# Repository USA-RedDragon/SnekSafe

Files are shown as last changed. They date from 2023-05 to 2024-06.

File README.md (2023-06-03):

# SnekSafe

Keep your snek safe by controlling temperature and lighting.

## Assembled v1.1 Board

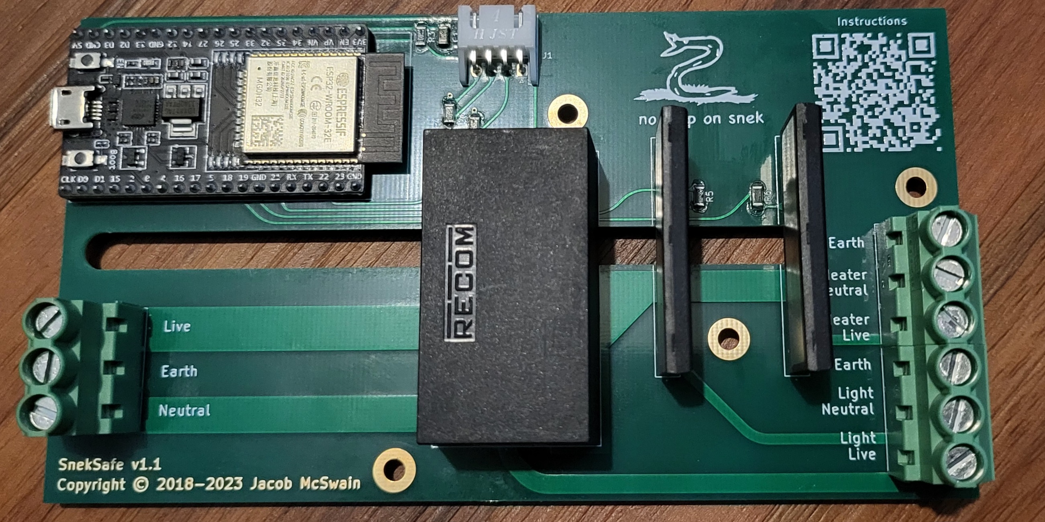
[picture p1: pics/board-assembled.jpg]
v1.1 assembled

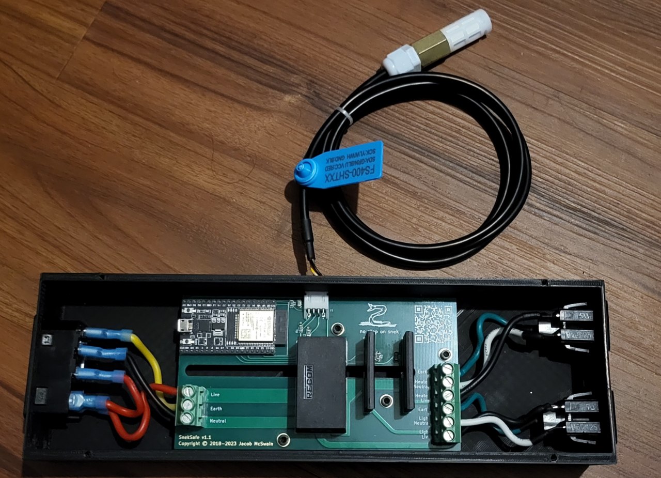
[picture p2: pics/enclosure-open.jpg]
v1.1 assembled in enclosure


## Board Renders

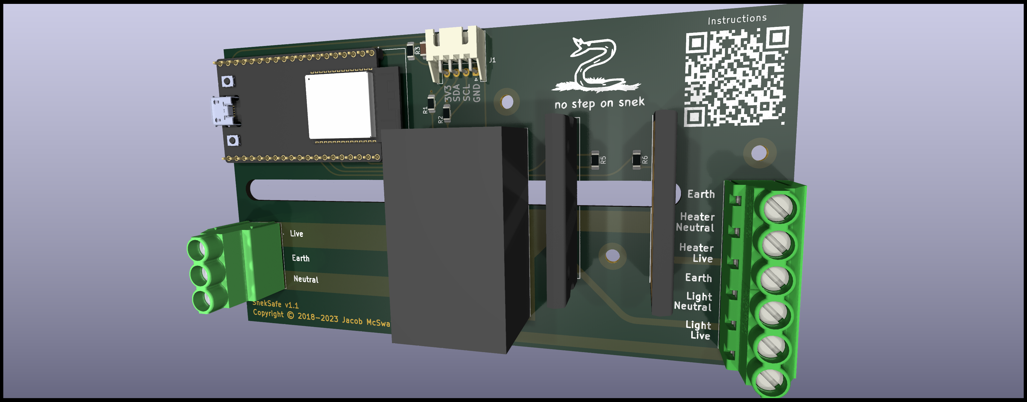
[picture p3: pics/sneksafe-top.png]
Board Top

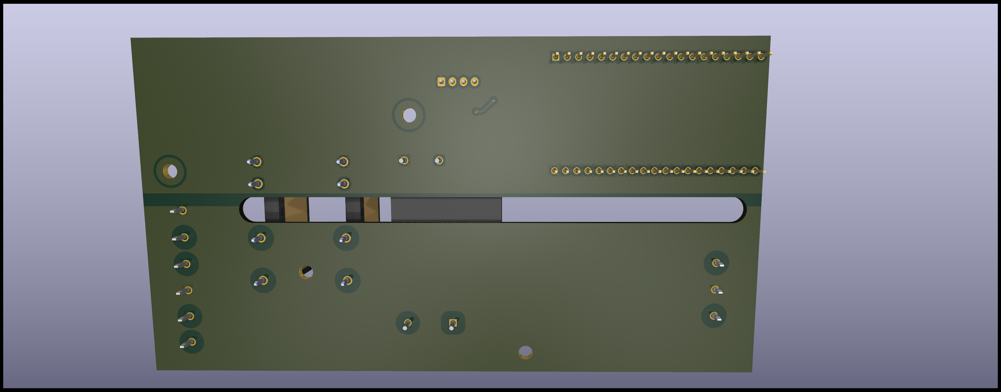
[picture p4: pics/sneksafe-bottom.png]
Board Bottom

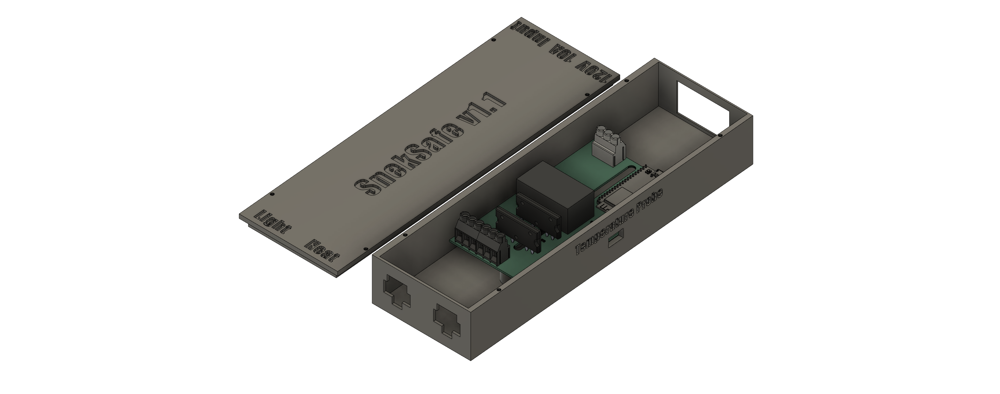
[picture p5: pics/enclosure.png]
Board Enclosure


## Schematic

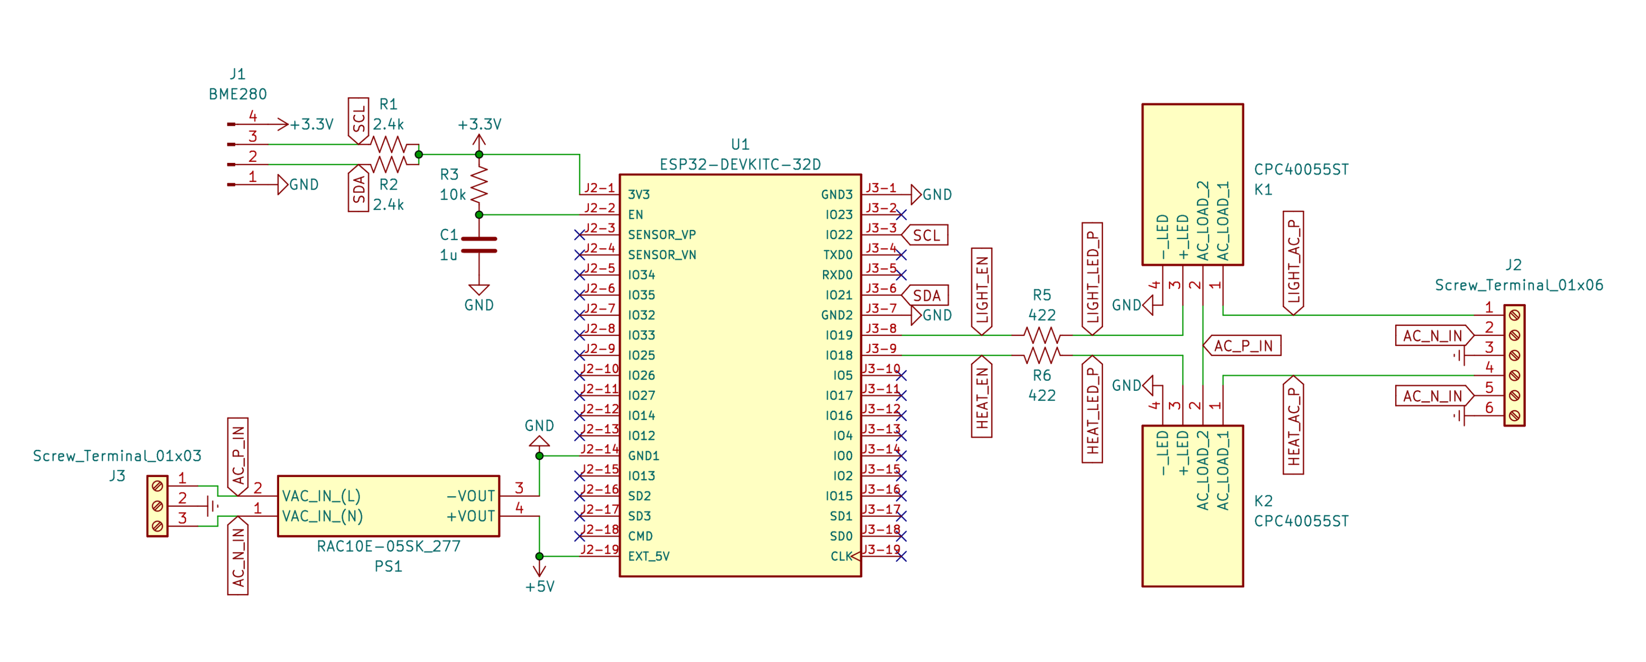
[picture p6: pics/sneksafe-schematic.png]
Schematic


## Board Layout

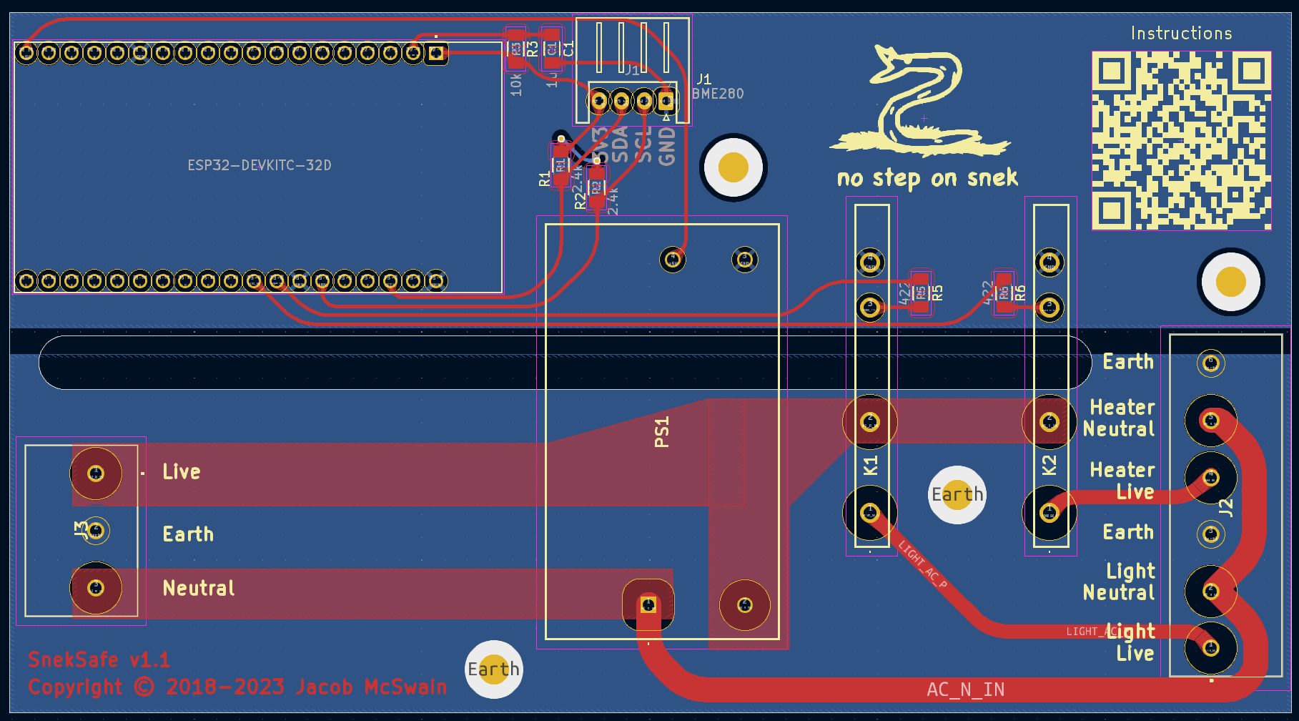
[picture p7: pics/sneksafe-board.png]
Board Layout


## Site Images

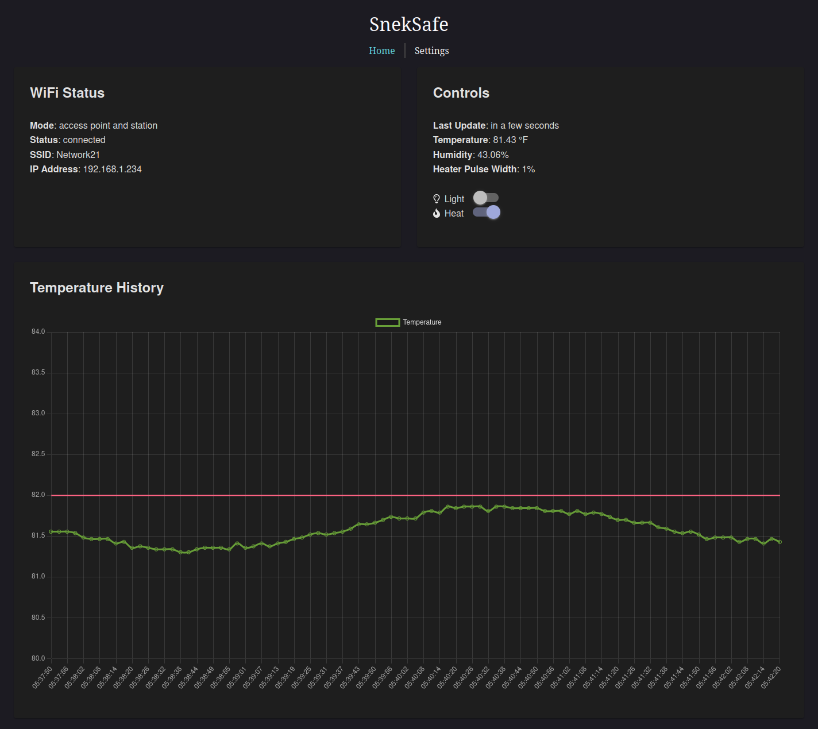
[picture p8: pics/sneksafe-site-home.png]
Home

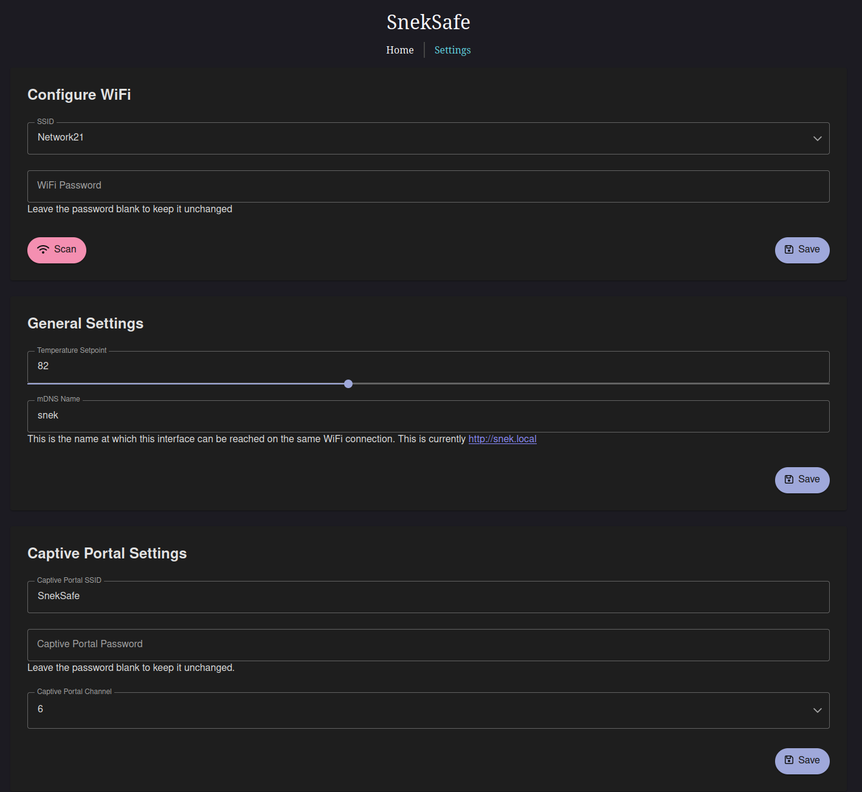
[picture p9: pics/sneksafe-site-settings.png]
Settings


## Parts not in the BOM that you might need

- 14AWG Silicone Wire - <https://www.amazon.com/dp/B089CRKSNN>
- Spade connectors for 14AWG - <https://www.amazon.com/dp/B08BZ972B5>
- 24AWG 4-conductor wire - <https://www.amazon.com/dp/B0BYDTCZ61>
- JST XH crimpers
- Heat shrink
- A 3d printer

## Cost

The one-off BOM cost, assuming you have spade connectors and 14AWG wire on hand is $121.25.

## On ESP32 choice

I chose the official ESP32-DevKitC-32E (ESP32-DevKitC V4) board due to quality. For some reason, on a cheaper NodeMCU ESP32S I was able to scan less WiFi networks and got a lower effective range.

## Premade Carts

A few items, such as the C13 AC cord, the C14 AC plug, and the panel mount AC outlets must be sourced on your own, as DigiKey and Mouser don't sell these commonly.

### JST XH Plug Parts

Mouser doesn't stock these: <https://www.digikey.com/short/1hzrmn3b>

### Mouser

<https://www.mouser.com/ProjectManager/ProjectDetail.aspx?AccessID=c3308da5f2>

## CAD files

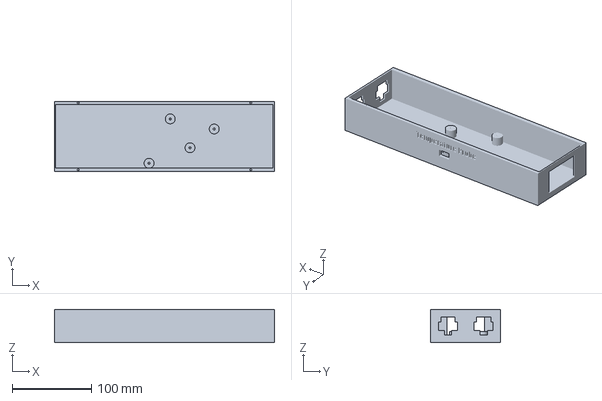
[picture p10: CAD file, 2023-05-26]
enclosure/body.3mf
278.0 x 89.0 x 42.0 mm

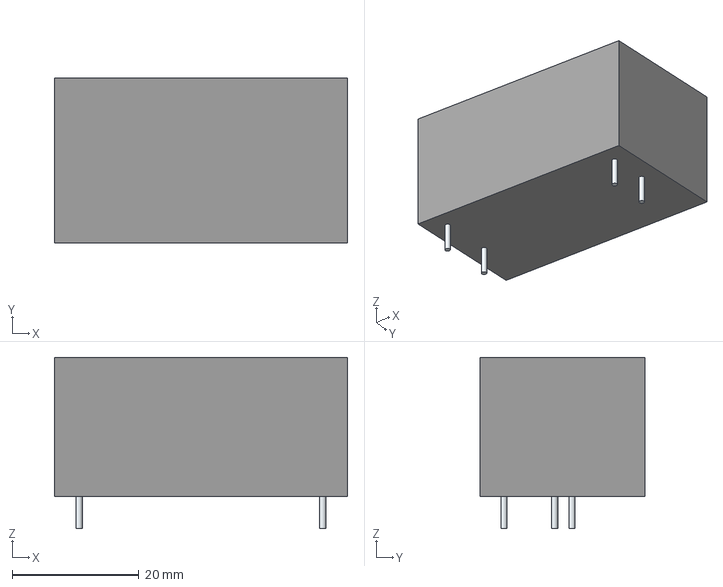
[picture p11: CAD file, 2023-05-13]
kicad/parts/RAC10E-05SK_277/RAC10E-05SK_277.stp
46.3 x 26.0 x 27.1 mm
Leads

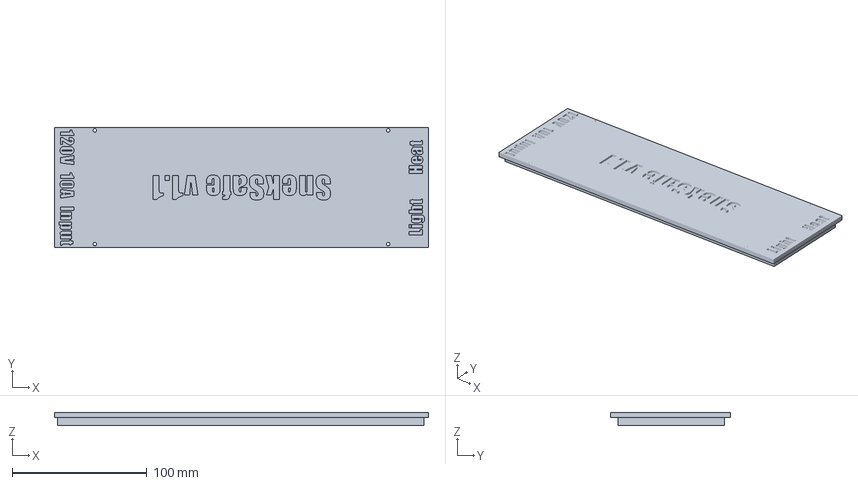
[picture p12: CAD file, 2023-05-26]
enclosure/lid.3mf
278.0 x 89.0 x 10.0 mm

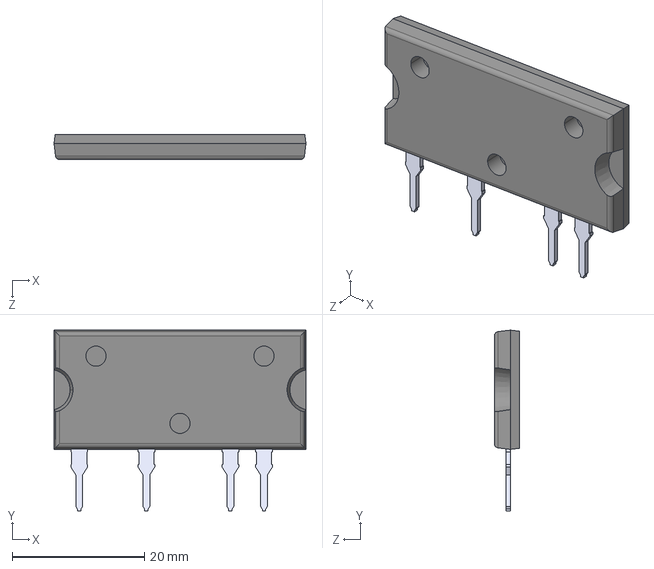
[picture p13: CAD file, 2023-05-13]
kicad/parts/CPC40055ST/CPC40055ST.stp
38.1 x 27.3 x 3.81 mm

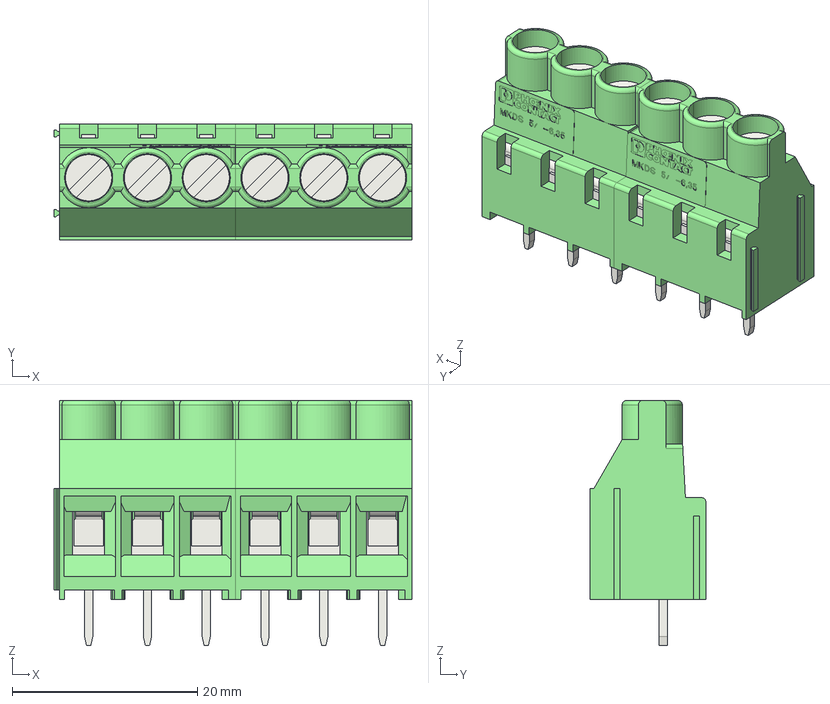
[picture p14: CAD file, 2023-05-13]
kicad/parts/Phoenix 1713969/1713969.stp
38.7 x 12.5 x 26.5 mm
KK_MKDS_5.1 x 6
AC_MKDS_5_Laengsschlitz x 6
LP_MKDS_5_5_00.1 x 6
AT_MKDS_5_6_35 x 2

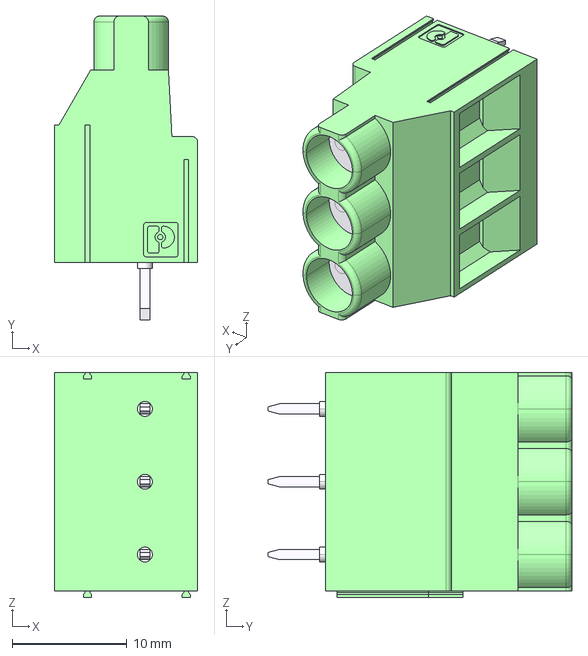
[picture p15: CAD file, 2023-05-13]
kicad/parts/Phoenix 1714968/1714968.stp
12.5 x 26.5 x 19.6 mm

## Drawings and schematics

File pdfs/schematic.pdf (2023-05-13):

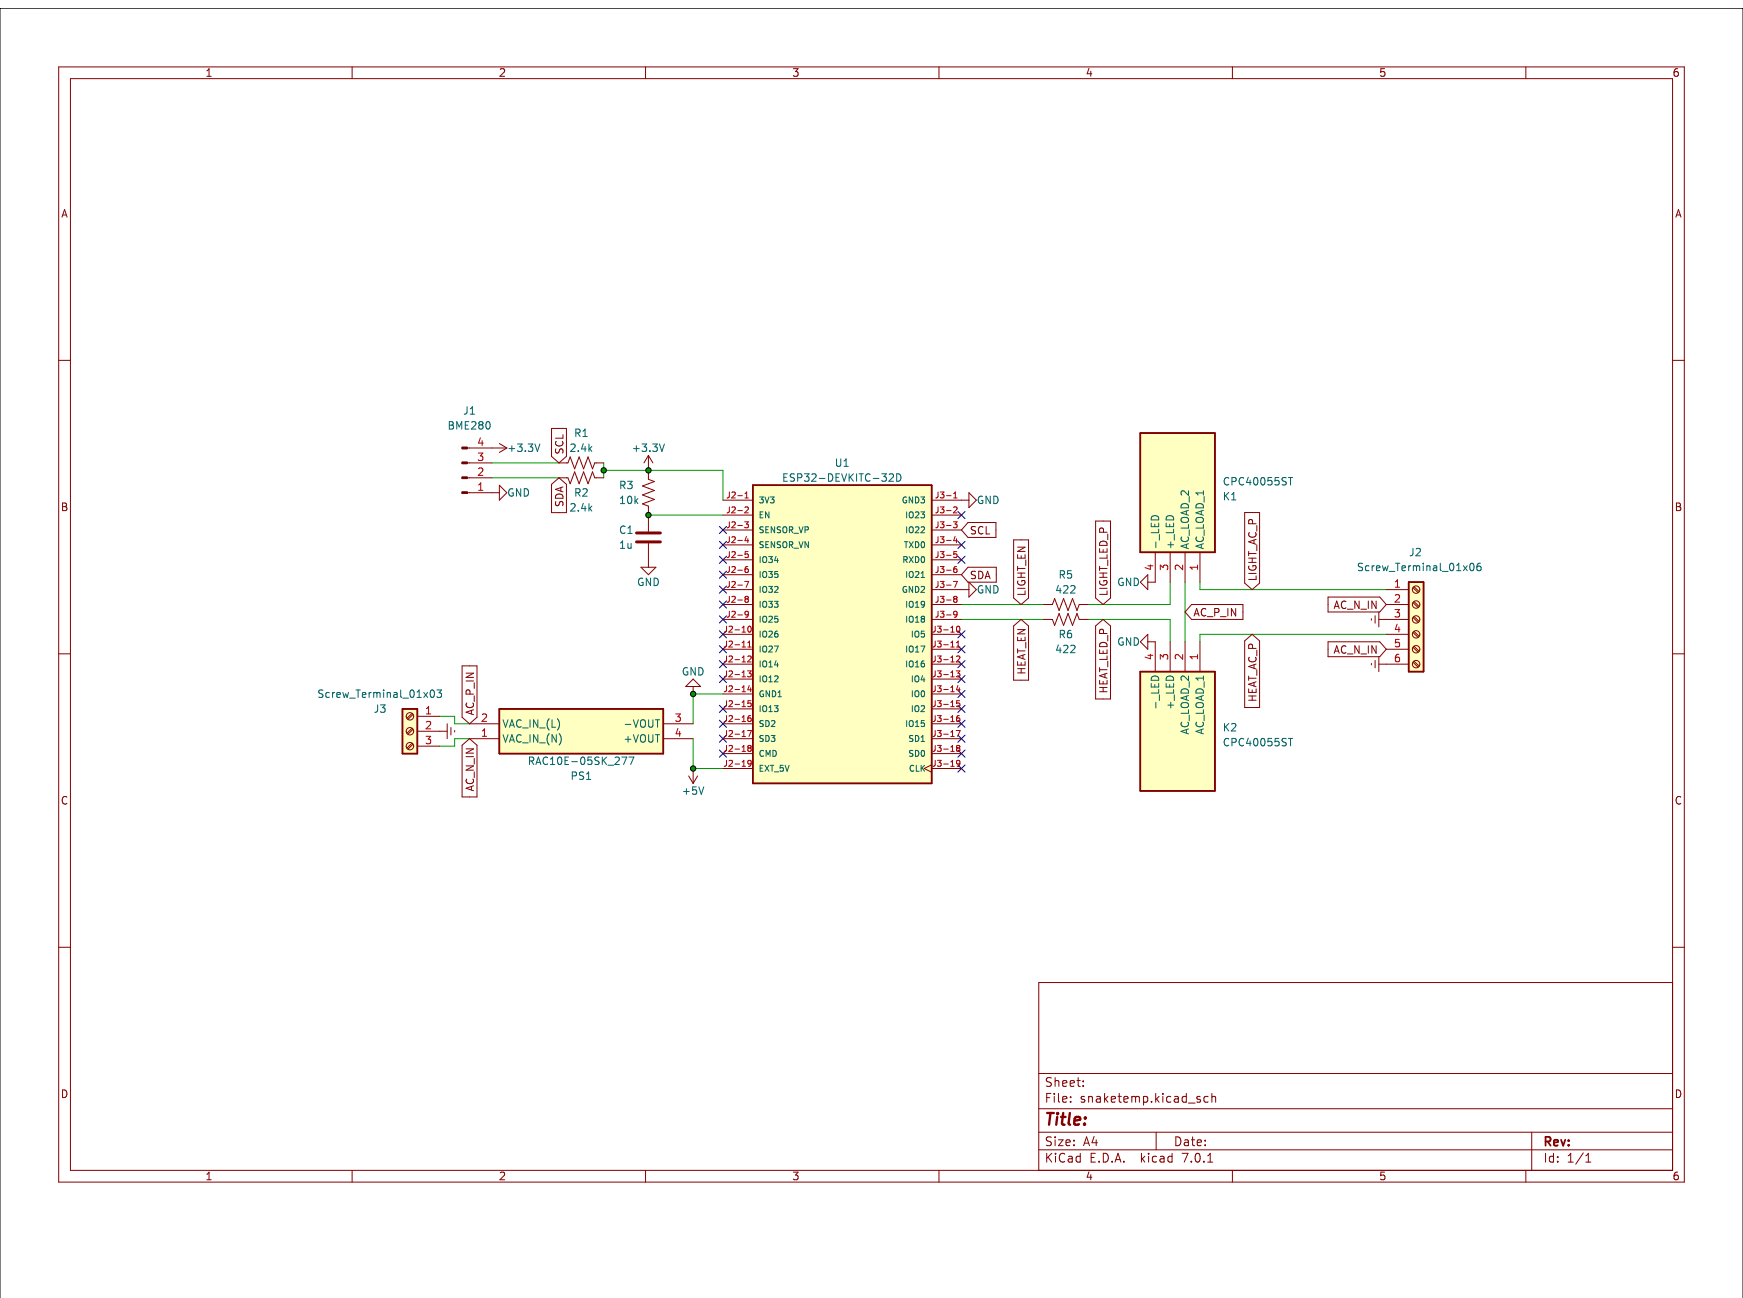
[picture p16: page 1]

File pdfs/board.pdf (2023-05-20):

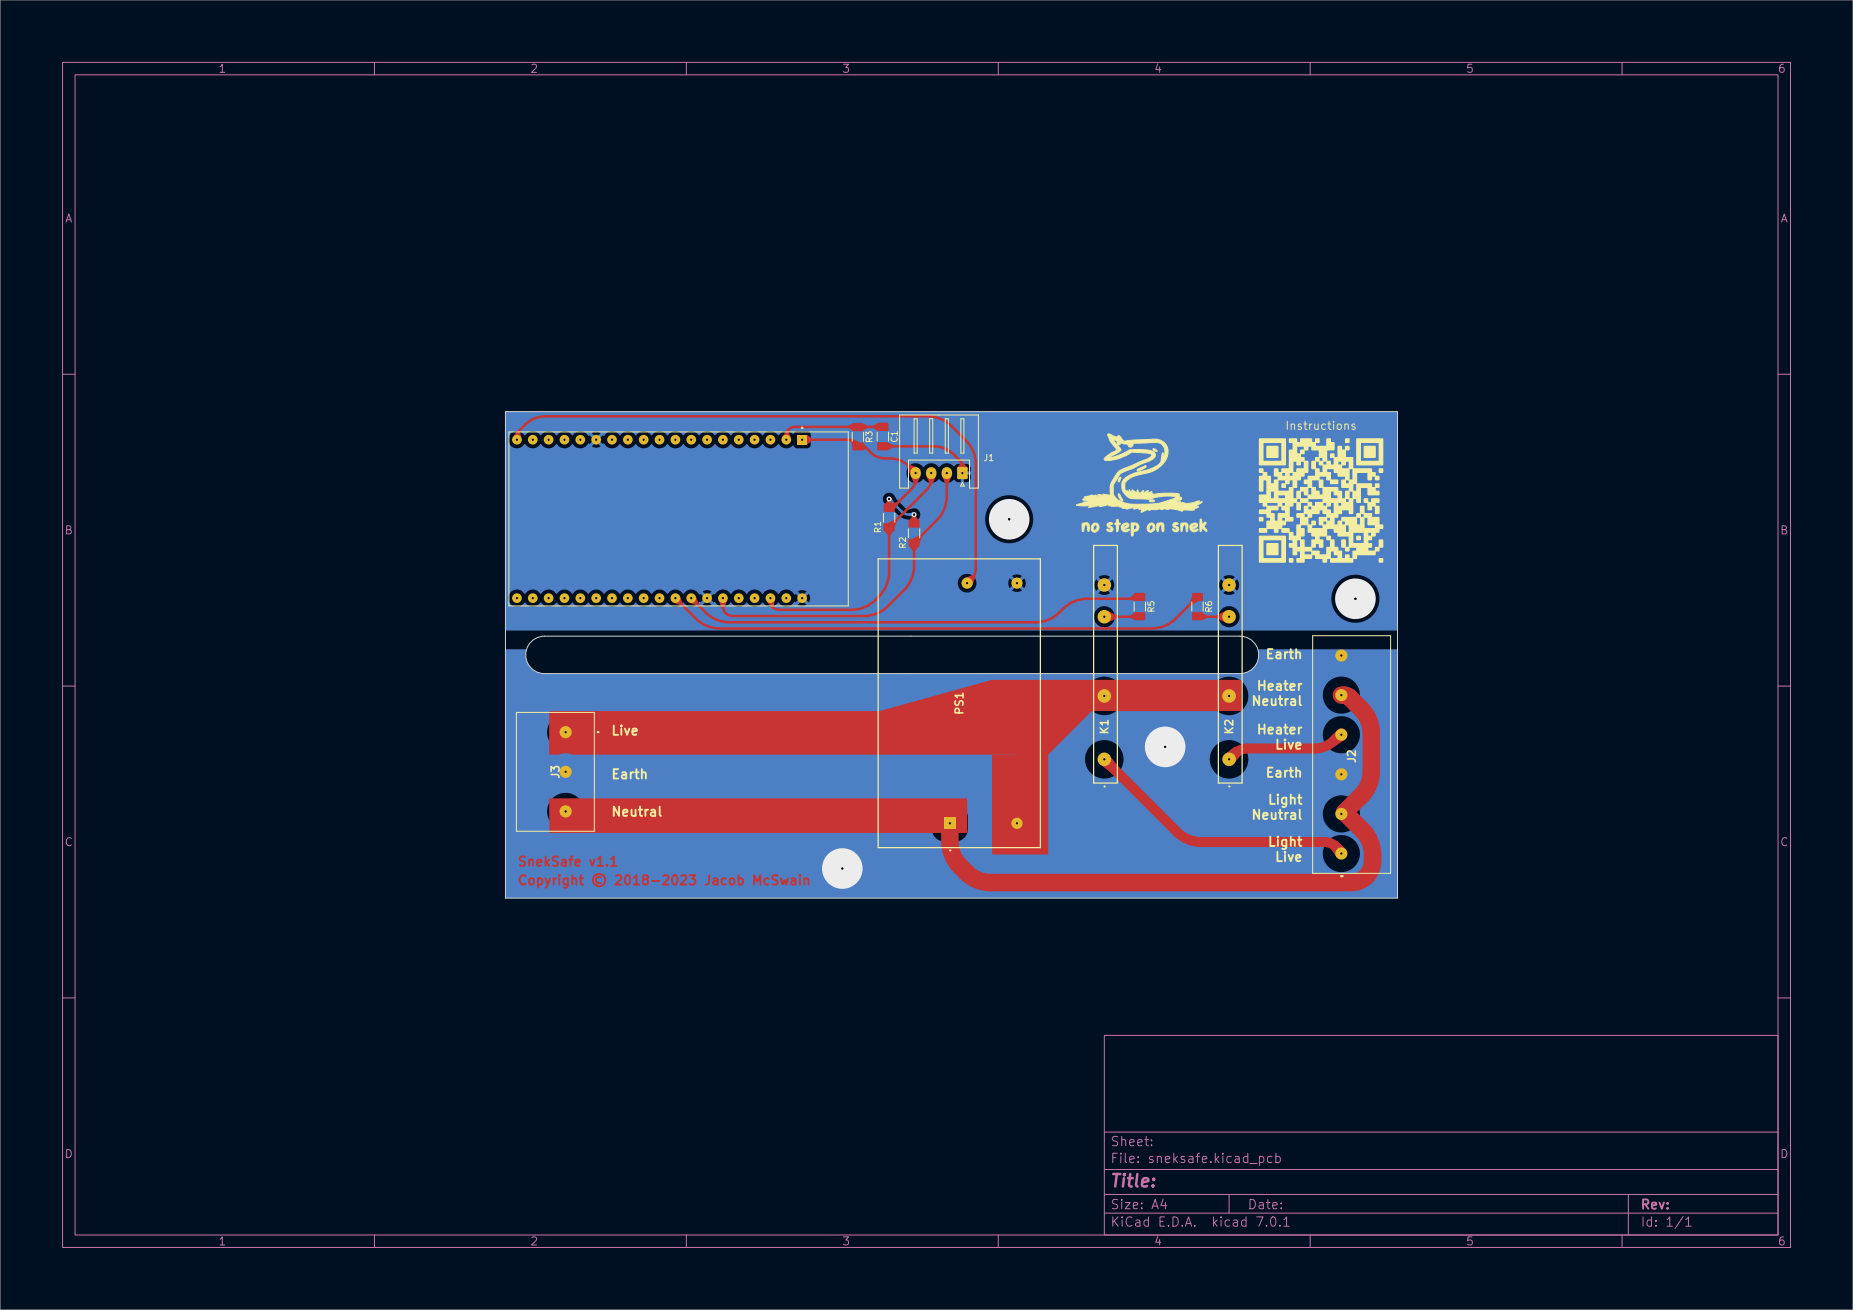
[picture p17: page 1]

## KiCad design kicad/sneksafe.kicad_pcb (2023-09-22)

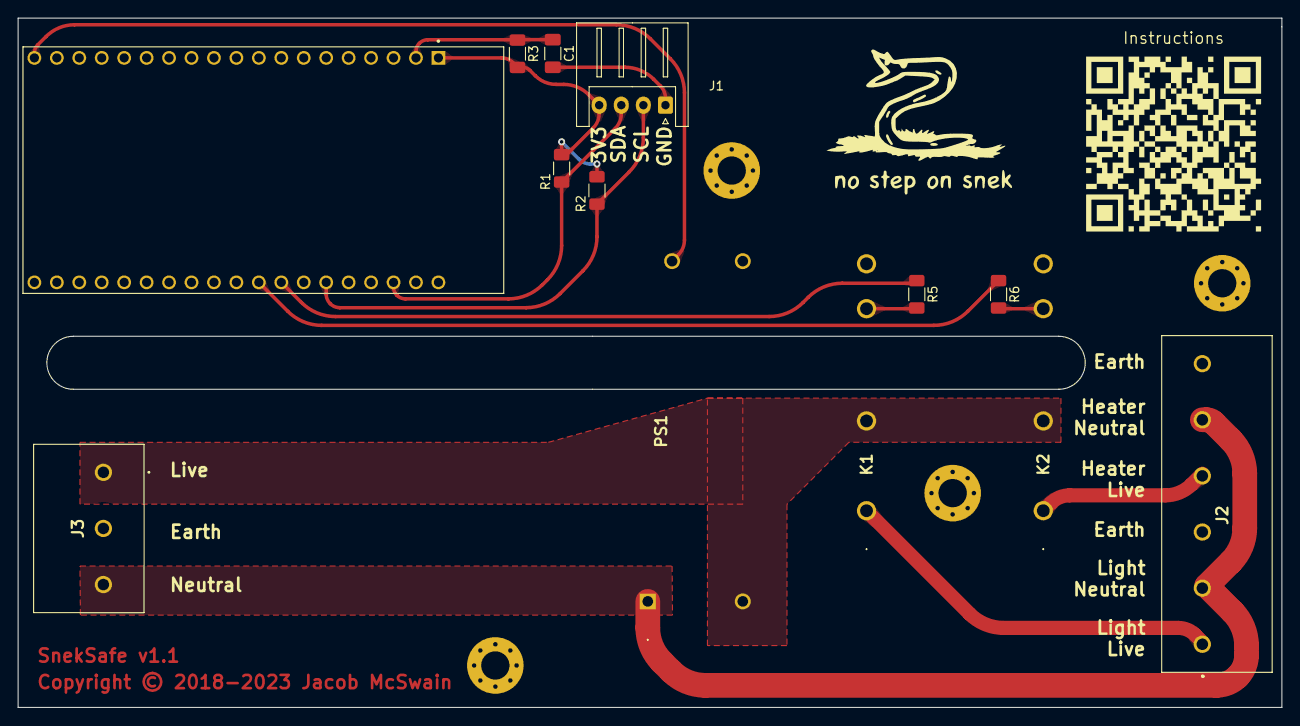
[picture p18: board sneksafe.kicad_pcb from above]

Board: 2 copper layers, 143.0 x 78.0 mm, 18 parts (0 on the bottom side), 15 nets.

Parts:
C1: 1u; C_1206_3216Metric_Pad1.33x1.80mm_HandSolder
J1: S4B-XH-A(LF)(SN); JST_XH_S4B-XH-A_1x04_P2.50mm_Horizontal
J2: Screw_Terminal_01x06; 1713969
J3: Screw_Terminal_01x03; 1714968
K1, K2: CPC40055ST
MH1, MH2: MountingHole_3.2mm_M3_Pad_Via
MH3, MH4: MountingHole_Pad; MountingHole_3.2mm_M3_Pad_Via
PS1: RAC10E-05SK_277; RAC10E05SK277
QR*****: Instructions; rickroll
R1, R2: 2.4k; R_1206_3216Metric_Pad1.30x1.75mm_HandSolder
R3: 10k; R_1206_3216Metric_Pad1.30x1.75mm_HandSolder
R5, R6: 422; R_1206_3216Metric_Pad1.30x1.75mm_HandSolder
U1: ESP32-DEVKITC-32D; MODULE_ESP32-DEVKITC-32D

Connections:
+3.3V: J1.4, R1.2, R2.2, R3.2, U1.J2-1 (3V3)
+5V: PS1.4 (+VOUT), U1.J2-19 (EXT_5V)
AC_N_IN: J2.2, J2.5, J3.3, PS1.1 (VAC_IN_(N))
AC_P_IN: J3.1, K1.2 (AC_LOAD_2), K2.2 (AC_LOAD_2), PS1.2 (VAC_IN_(L))
Earth: MH3.1, MH4.1
GND: C1.2, J1.1, K1.4 (-_LED), K2.4 (-_LED), PS1.3 (-VOUT), U1.J2-14 (GND1), U1.J3-1 (GND3), U1.J3-7 (GND2)
HEAT_AC_P: J2.4, K2.1 (AC_LOAD_1)
HEAT_EN: R6.1, U1.J3-9 (IO18)
HEAT_LED_P: K2.3 (+_LED), R6.2
LIGHT_AC_P: J2.1, K1.1 (AC_LOAD_1)
LIGHT_EN: R5.1, U1.J3-8 (IO19)
LIGHT_LED_P: K1.3 (+_LED), R5.2
unnamed: C1.1, R3.1, U1.J2-2 (EN)
SCL: J1.3, R1.1, U1.J3-3 (IO22)
SDA: J1.2, R2.1, U1.J3-6 (IO21)

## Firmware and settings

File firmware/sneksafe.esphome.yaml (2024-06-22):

substitutions:
  light_pin: "19"
  heater_pin: "18"
  sda_pin: "21"
  scl_pin: "22"

  name: sneksafe
  friendly_name: SnekSafe

esphome:
  name: ${name}
  friendly_name: ${friendly_name}
  on_boot:
    priority: 0
    then:
      - climate.control:
          id: pid_controller
          mode: HEAT
          target_temperature: !lambda "return id(temperature_setpoint);"
      - number.set:
          id: temperature_setpoint_value
          value: !lambda "return (id(temperature_setpoint)*1.8)+32;"
      - select.set:
          id: light_on_minute
          option:  !lambda "return esphome::str_sprintf(\"%02d\", id(light_on_mm));"
      - select.set:
          id: light_on_hour
          option:  !lambda "return esphome::str_sprintf(\"%02d\", id(light_on_hh));"
      - select.set:
          id: light_off_minute
          option:  !lambda "return esphome::str_sprintf(\"%02d\", id(light_off_mm));"
      - select.set:
          id: light_off_hour
          option:  !lambda "return esphome::str_sprintf(\"%02d\", id(light_off_hh));"
      - globals.set:
          id: initialized
          value: "true"

esp32:
  board: az-delivery-devkit-v4

wifi:
  ap:
    ssid: ${name}
    password: snekysnek

captive_portal:

ota:
  platform: esphome

text_sensor:
  - platform: wifi_info
    ip_address:
      name: IP Address
    ssid:
      name: Network
    mac_address:
      name: MAC Address

script:
  # Called every minute to check if the light should change state
  - id: check_light
    mode: restart
    then:
      lambda: |-
        #include <ctime>
        if (!id(initialized)) {
           return;
        }

        // Check if the we know what time it is.
        auto now = id(time_sntp).now();
        if (!now.is_valid()) { return; }

        // Get the current timestamp.
        if ((int)id(light_on_hh) == now.hour && (int)id(light_on_mm) == now.minute) {
          id(light_switch).turn_on();
          return;
        }

        // We're within the minute to turn off
        if ((int)id(light_off_hh) == now.hour && (int)id(light_off_mm) == now.minute) {
          id(light_switch).turn_off();
          return;
        }

time:
  - platform: sntp
    id: time_sntp
    timezone: CST6CDT,M3.2.0,M11.1.0
    update_interval: 600s
    on_time:
      seconds: 0
      minutes: "*"
      then:
        script.execute: check_light

i2c:
  sda: ${sda_pin}
  scl: ${scl_pin}

sensor:
  - platform: template
    name: "Temperature"
    id: temperature
    unit_of_measurement: °F
  - platform: sht3xd
    temperature:
      id: raw_temperature
      on_value:
        then:
          - sensor.template.publish:
              id: temperature
              state: !lambda 'return (x*1.8)+32;'
    humidity:
      name: "Humidity"
    address: 0x44
    update_interval: 100ms
    heater_enabled: true
    
  - platform: uptime
    name: Uptime Sensor
    update_interval: 1s
  - name: Timestamp
    platform: template
    lambda: 'return id(time_sntp).now().timestamp;'
    internal: false
    device_class: timestamp
    entity_category: diagnostic
    accuracy_decimals: 0
    update_interval: 1s

  - platform: wifi_signal
    name: "WiFi Signal dB"
    id: wifi_signal_db
    update_interval: 3s
    entity_category: "diagnostic"

  - platform: copy
    source_id: wifi_signal_db
    name: "WiFi Signal Percent"
    filters:
      - lambda: return min(max(2 * (x + 100.0), 0.0), 100.0);
    unit_of_measurement: "%"
    entity_category: "diagnostic"

  - platform: pid
    name: "PID KP"
    type: KP
  - platform: pid
    name: "PID KI"
    type: KI
  - platform: pid
    name: "PID KD"
    type: KD
  - platform: pid
    name: "PID P"
    type: PROPORTIONAL
  - platform: pid
    name: "PID I"
    type: INTEGRAL
  - platform: pid
    name: "PID D"
    type: DERIVATIVE
  - platform: pid
    name: "Heat Output"
    type: HEAT
  - platform: pid
    name: "PID Error"
    type: ERROR

globals:
  - id: temperature_setpoint
    type: float
    restore_value: yes
    initial_value: "27.22"
  - id: initialized
    type: bool
    restore_value: false
    initial_value: "false"
  # The time at which the light should turn on
  - id: light_on_hh
    type: int
    restore_value: yes
    initial_value: "9"
  - id: light_on_mm
    type: int
    restore_value: yes
    initial_value: "30"
  # The time at which the light should turn off
  - id: light_off_hh
    type: int
    restore_value: yes
    initial_value: "21"
  - id: light_off_mm
    type: int
    restore_value: yes
    initial_value: "30"
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

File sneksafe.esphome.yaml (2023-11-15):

substitutions:
  light_pin: "19"
  heater_pin: "18"
  sda_pin: "21"
  scl_pin: "22"

  name: sneksafe
  friendly_name: SnekSafe

esphome:
  name: ${name}
  friendly_name: ${friendly_name}

esp32:
  board: az-delivery-devkit-v4

logger:

wifi:
  ssid: !secret sneksafe_wifi_ssid
  password: !secret sneksafe_wifi_password

  ap:
    ssid: ${name}
    password: !secret sneksafe_ap_password

captive_portal:

ota:

text_sensor:
  - platform: wifi_info
    ip_address:
      name: ESP IP Address
    ssid:
      name: ESP Connected SSID
    bssid:
      name: ESP Connected BSSID
    mac_address:
      name: ESP Mac Wifi Address
    dns_address:
      name: ESP DNS Address
    
time:
  - platform: sntp
    timezone: America/New_York
    on_time:
      # 10pm
      - cron: '00 00 22 * * *'
        then:
          - switch.turn_off: light
      # 10am
      - cron: '00 00 10 * * *'
        then:
          - switch.turn_on: light

i2c:
  sda: ${sda_pin}
  scl: ${scl_pin}

sensor:
  - platform: sht3xd
    temperature:
      name: "Temperature"
      id: temperature
    humidity:
      name: "Humidity"
    address: 0x44
    update_interval: 100ms
    heater_enabled: true
    
  - platform: uptime
    name: Uptime Sensor
    update_interval: 1s

  - platform: wifi_signal
    name: "WiFi Signal dB"
    id: wifi_signal_db
    update_interval: 3s
    entity_category: "diagnostic"

  - platform: copy
    source_id: wifi_signal_db
    name: "WiFi Signal Percent"
    filters:
      - lambda: return min(max(2 * (x + 100.0), 0.0), 100.0);
    unit_of_measurement: "Signal %"
    entity_category: "diagnostic"

switch:
  - platform: gpio
    name: "Light"
    id: light
    pin: ${light_pin}

output:
  - platform: sigma_delta_output
    update_interval: 500ms
    id: heater
    pin: ${heater_pin}

climate:
  - platform: pid
    name: "PID Controller"
    id: pid_controller
    sensor: temperature
    heat_output: heater
    default_target_temperature: 81°F
    control_parameters:
      kp: 0.0
      ki: 0.0
      kd: 0.0
      output_averaging_samples: 5
      derivative_averaging_samples: 5
    deadband_parameters:
      threshold_high: 0.5°F
      threshold_low: -0.5°F

button:
  - platform: template
    name: "PID Autotune"
    on_press:
      - climate.pid.autotune: pid_controller

web_server:
  port: 80
  local: true

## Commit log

2023-05-18 board v1.1: add mounting holes and update QR link
    [sneksafe.kicad_pcb]
2023-05-19 fw: We'll need ArduinoJson
2023-05-19 fw: rename esp32dev -> esp32
2023-05-19 fw: Use specific esp32 board
2023-05-19 fw: Use custom partitions
    [partitions.csv]
2023-05-19 fw: wifi: fixup for esp32
2023-05-20 fw: add PID
2023-05-20 fw: api: expose PID tuneables
2023-05-20 fw: fix PID addressing
2023-05-20 frontend: add PID tuneables
2023-05-20 fw: turn off heaters on boot
2023-05-20 fw: pid: update api
2023-05-20 fw: api: settings: set I term limits for pid
2023-05-20 Add an enclosure
    [body.3mf, enclosure.step, lid.3mf]
2023-05-23 Add assembled board photo (#1)
2023-05-26 enclosure: Update fitment and add debossed labels
    [body.3mf, enclosure.step, lid.3mf]
2023-05-26 Add open enclosure photo
2023-05-28 fw: Add factory reset on boot button
2023-05-28 fw: Implement on/off timer
2023-05-28 fw: captive portal + pid: add end()
2023-05-28 fw: implement arduino ota
2023-05-28 fw: print version to serial on startup
2023-05-28 fw: pid: don't run if not started
2023-05-28 fw: pass temperatureSetpoint in state
2023-05-28 frontend: Add temperature setpoint
2023-05-28 fw: shorten pid loop to 10s
2023-05-28 fw: compute pid on start
2023-05-28 fw: 3s pid loop
2023-05-28 fw: separate PWM from 10ms timer
2023-05-30 frontend: remove heat toggle and make compact
2023-05-30 fw: Reconfigure timing
    - 120hz PWM
    - 100ms temperature readings
    - 500ms PID loop
    - 10s UI updates
    - 1m heater loop
2023-05-30 fw: fix i2c reads
2023-05-30 fw: fix version print
2023-06-01 fw: gzip compress frontend
    [partitions.csv]
2023-06-03 pcb: prepare for CI-generated BOM
    [bom.csv, sneksafe.kicad_pcb, sneksafe.kicad_sch]
2023-06-04 Add Kiri for visual kicad diff
2023-06-04 kicad: move some stuff around
    [sneksafe.kicad_sch]
2023-09-22 Prepare for kibot
    [sneksafe.kicad_pcb, sneksafe.kicad_sch]
2023-09-22 kicad: fixups
    [sneksafe.kicad_pcb, sneksafe.kicad_sch]
2023-09-22 kicad: fix DRC silkscreen clipping
    [sneksafe.kicad_pcb]
2023-09-22 chore(deps): update dependency fbiego/esp32time to v2.0.4
2023-09-22 chore(deps): update dependency bblanchon/arduinojson to v6.21.3
2023-09-22 chore(deps): update dependency powerbroker2/ardupid to v0.2.1
2023-10-09 chore(deps): update ghcr.io/inti-cmnb/kicad7_auto:latest docker digest to 0a5e846
2023-10-18 chore(deps): update ghcr.io/inti-cmnb/kicad7_auto:latest docker digest to 595bdcc
2023-10-23 chore(deps): update ghcr.io/inti-cmnb/kicad7_auto:latest docker digest to eee108c
2023-12-12 chore(deps): update ghcr.io/inti-cmnb/kicad7_auto:latest docker digest to e2ff975
2023-12-20 chore(deps): update ghcr.io/inti-cmnb/kicad7_auto:latest docker digest to e245e36
2024-01-04 chore(deps): update ghcr.io/inti-cmnb/kicad7_auto:latest docker digest to 1af32f4
2024-01-09 chore(deps): update ghcr.io/inti-cmnb/kicad7_auto:latest docker digest to a0b25ce
2024-01-19 ci: pr-kicad-diff: ubuntu 22.04
2024-01-19 ci: pr-close-kicad-delete-page: ubuntu 22.04
2024-01-22 chore(deps): update ghcr.io/inti-cmnb/kicad7_auto:latest docker digest to 5fb7254
2024-02-02 chore(deps): update ghcr.io/inti-cmnb/kicad7_auto:latest docker digest to ec5282f
2024-02-14 chore(deps): update ghcr.io/inti-cmnb/kicad7_auto:latest docker digest to 62b7efc
2024-03-06 chore(deps): update ghcr.io/inti-cmnb/kicad7_auto:latest docker digest to 1ad631e
2024-03-22 chore(deps): update ghcr.io/inti-cmnb/kicad7_auto:latest docker digest to 35115ab
2024-03-31 chore(deps): update ghcr.io/inti-cmnb/kicad7_auto:latest docker digest to d6cdbe3
2024-04-23 chore(deps): update ghcr.io/inti-cmnb/kicad7_auto:latest docker digest to 7897248
2024-04-23 chore(deps): update ghcr.io/inti-cmnb/kicad7_auto:latest docker digest to b082a27
2024-05-03 chore(deps): update ghcr.io/inti-cmnb/kicad7_auto:latest docker digest to ab2b349
2024-05-06 chore(deps): update ghcr.io/inti-cmnb/kicad7_auto:latest docker digest to fb37880
2024-06-19 chore(deps): update ghcr.io/inti-cmnb/kicad7_auto:latest docker digest to ccb5348
2024-08-11 chore(deps): update ghcr.io/inti-cmnb/kicad7_auto:latest docker digest to 78f021e

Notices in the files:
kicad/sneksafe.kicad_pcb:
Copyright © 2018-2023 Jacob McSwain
